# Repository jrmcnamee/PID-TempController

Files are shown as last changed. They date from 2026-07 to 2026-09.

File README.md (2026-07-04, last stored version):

# PID-TempController
Lab project to control the temperature of water using an Arduino and a PID algorithm

## Proportional-Integral-Derivative Algorithms
A Proportional-Integral-Derivative Algorithm can be used in controllers to minimize the difference betweent the output and the desired state of the system. A PID is a classic closed-loop feedback system, meaning it takes an input and then systematically compares current state to its input over time. The image below shows a simple version of a closed loop system. The PID is simple and easy to implement, making it an attractive choice for many automated processes.



There are many applications for the PID controller, but it's used most often in regulation. For example, the current goal for my PID is to simply regulate water temperature using a probe and heating rod.

### Walking 100 meters; example
So imagine you need to walk forward 100 meters for a sobriety test (**that is one demanding cop!**). Of course, you're sober, but the cop is having a bad night so he demands you walk exactly 100 meters. You only pass if you stop within 0.1 meters of the goal. If you think about it, this is a clever test, because drunk people do not understand control systems! Another rule: **you cannot stop until you're done, reverse, or speed up after slowing down!** This'll come into play in a second.

So, how do you proceed? Well, the cop gives you a watch that tells you your position every second, and you have a brain that sets your velocity with devastating accuracy. Thats easy! Just stop when the watch says 99.9. But wait, theres a caveat: the watch only updates every second. One miss-step near the goal and you fail, and the watch won't update fast enough to  So what you do first is select your **gain**. The gain is very simple: select your gain, multipy it by your distance, and then thats the new velocity you will walk. Since a fast human walking pace is 2.5 meters per second, you select a gain of 0.025, as 100 meters * 0.025 $$s^{-1}$$ is 2.5 m/s. Your distance to time graph will look something like this.

Your position will approach the goal asymptotically until you get within 0.1 meters. The cop is stunned, but daps you up for your incredible math abilities. Thankfully for you, you simple cannot walk fast enough to blow past your target. However, if it *were* possible to select a gain of, say, 1.9, your graph would look like 

So lets talk a little bit more of P, I, and D.
Note that in this example, you technically need that tolerance the cop gave, otherwise you never will really arrive at the destination.



## Proportional Gain, K<sub>p</sub>
Propotional gain was exemplified just before this in the walking example. Its a good way to correct your behavior as you approach the target. However, there are many ways for this to go wrong. Imagine that instead of walking, you're climbing, and gain * error sets the force you climb with. Obviously, you will stop dead in your tracks if the force you move up with ever equals the force of gravity, or your weight. This is called steady state error, and it will result in you never making it to the target. Also, think about it for a heating apparatus: if a certain amount of applied voltage corresponds to a certain amount of heat loss per minute and the rate of heat emmission by the heated system ever becomes equal, you'll be screwed. Whoops!

Proportional gain cannot account for steady state error, or mitigate oscillations. It's the principal component of gain, and extremely influential in the PID. Play around with it using my python code for a basic PID, it'll really shock you how much it governs the system! Try to see if you can get it to reach a steady state (hint: add a term of pushback against proportional gain!)

## Integral Gain, K<sub>i</sub>

Integral gain stockpiles error and provides a proportional signal to the integral over the time. Seems simple, right? This is a great solution to the steady state error connundrum, as persistant, constant error ultimately results in the increase of the provided signal, preventing stability anywhere other than the target. An appropriate integral gain coefficient will make a clean descent/ascent to the target, but one too large will result in "integral windup" which is this fun oscillating value over to the right. The integral and proportional terms should not exist without one another, as they cover eachothers' bases very well.

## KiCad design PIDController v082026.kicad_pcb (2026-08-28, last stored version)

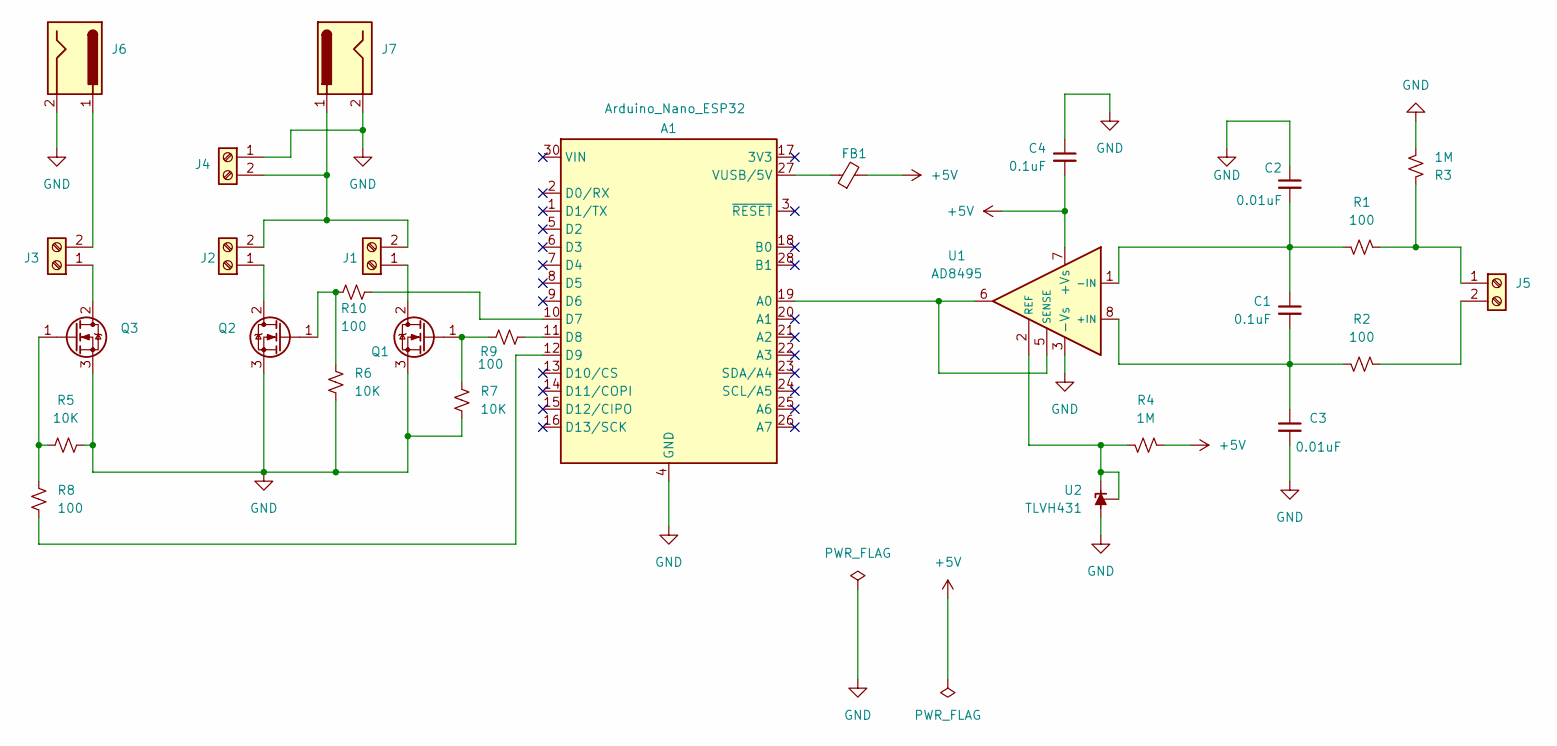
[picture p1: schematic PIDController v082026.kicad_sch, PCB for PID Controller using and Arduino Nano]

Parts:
A1: Arduino_Nano_ESP32; Arduino_Nano
C1, C4: 0.1uF; C_0603_1608Metric
C2, C3: 0.01uF; C_0603_1608Metric
FB1: FerriteBead_Small; L_0603_1608Metric
J1, J2, J3, J4, J5: Screw_Terminal_01x02; TerminalBlock_Phoenix_MKDS-1,5-2_1x02_P5.00mm_Horizontal
J6, J7: Jack-DC; BarrelJack_CUI_PJ-063AH_Horizontal
Q1, Q2, Q3: IRLZ44N; TO-220-3_Vertical
R1, R2, R8, R9, R10: 100; R_0603_1608Metric
R3, R4: 1M; R_0603_1608Metric
R5, R6, R7: 10K; R_0603_1608Metric
U1: AD8495; MSOP-8_3x3mm_P0.65mm
U2: TLVH431; SOT-23

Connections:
+5V: C4.2, FB1.2, R4.1, U1.7 (+Vs)
GND: A1.4 (GND), A1.29 (GND), C2.1, C3.2, C4.1, J4.1, J6.2, J7.2, Q1.3 (S), Q2.3 (S), Q3.3 (S), R3.2, R5.1, R6.2, R7.2, U1.3 (-Vs), U2.3 (A)
unnamed: A1.19 (A0), U1.5 (SENSE), U1.6
unnamed: A1.10 (D7), R10.2
unnamed: A1.11 (D8), R9.2
unnamed: A1.12 (D9), R8.2
unnamed: A1.27 (VUSB/5V), FB1.1
unnamed: J1.1, Q1.2 (D)
unnamed: J1.2, J2.2, J4.2, J7.1
unnamed: J2.1, Q2.2 (D)
unnamed: J3.1, Q3.2 (D)
unnamed: J3.2, J6.1
unnamed: J5.1, R1.1, R3.1
unnamed: J5.2, R2.1
unnamed: Q1.1 (G), R7.1, R9.1
unnamed: Q2.1 (G), R6.1, R10.1
unnamed: Q3.1 (G), R5.2, R8.1
unnamed: C1.2, C3.1, R2.2, U1.8 (+IN)
unnamed: C1.1, C2.2, R1.2, U1.1 (-IN)
unnamed: R4.2, U1.2 (REF), U2.1 (K), U2.2 (REF)

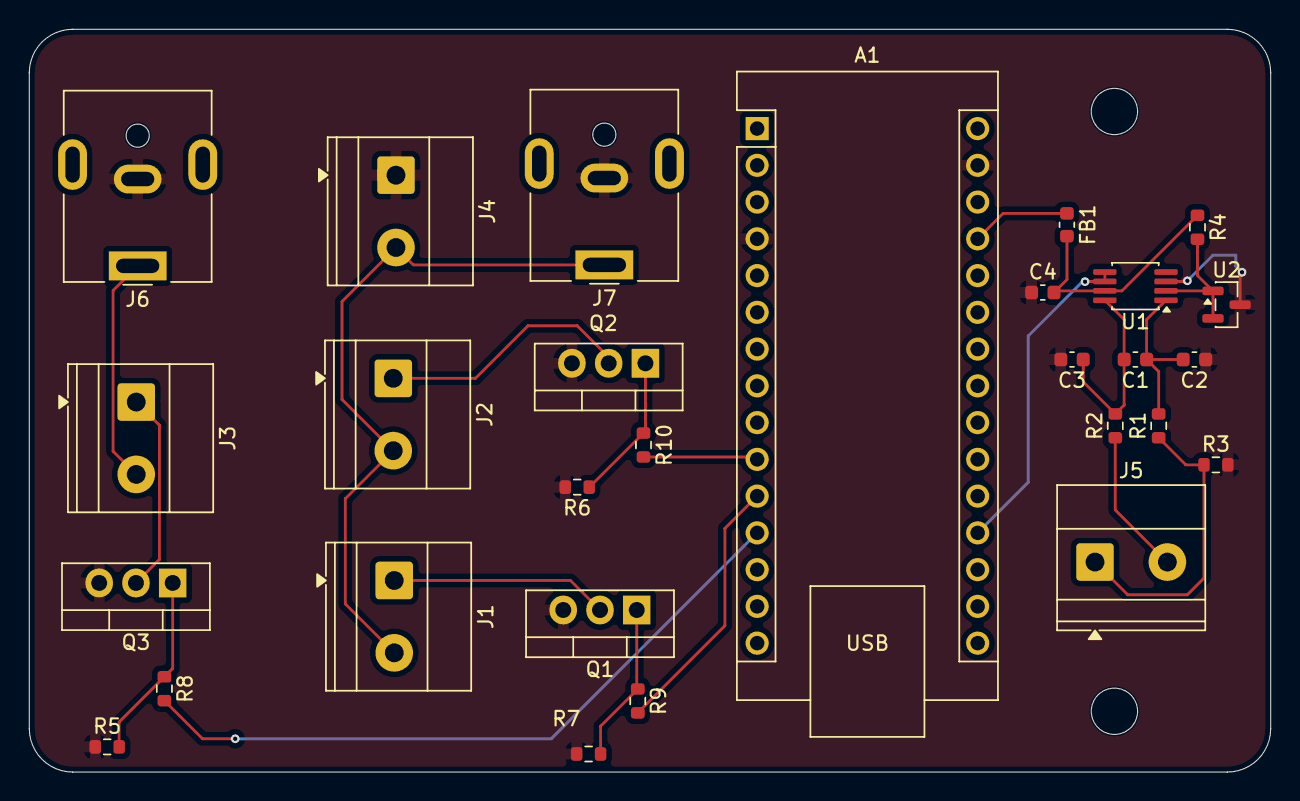
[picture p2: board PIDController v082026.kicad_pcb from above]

Board: 2 copper layers, 85.8 x 51.3 mm, 28 parts (0 on the bottom side), 20 nets.

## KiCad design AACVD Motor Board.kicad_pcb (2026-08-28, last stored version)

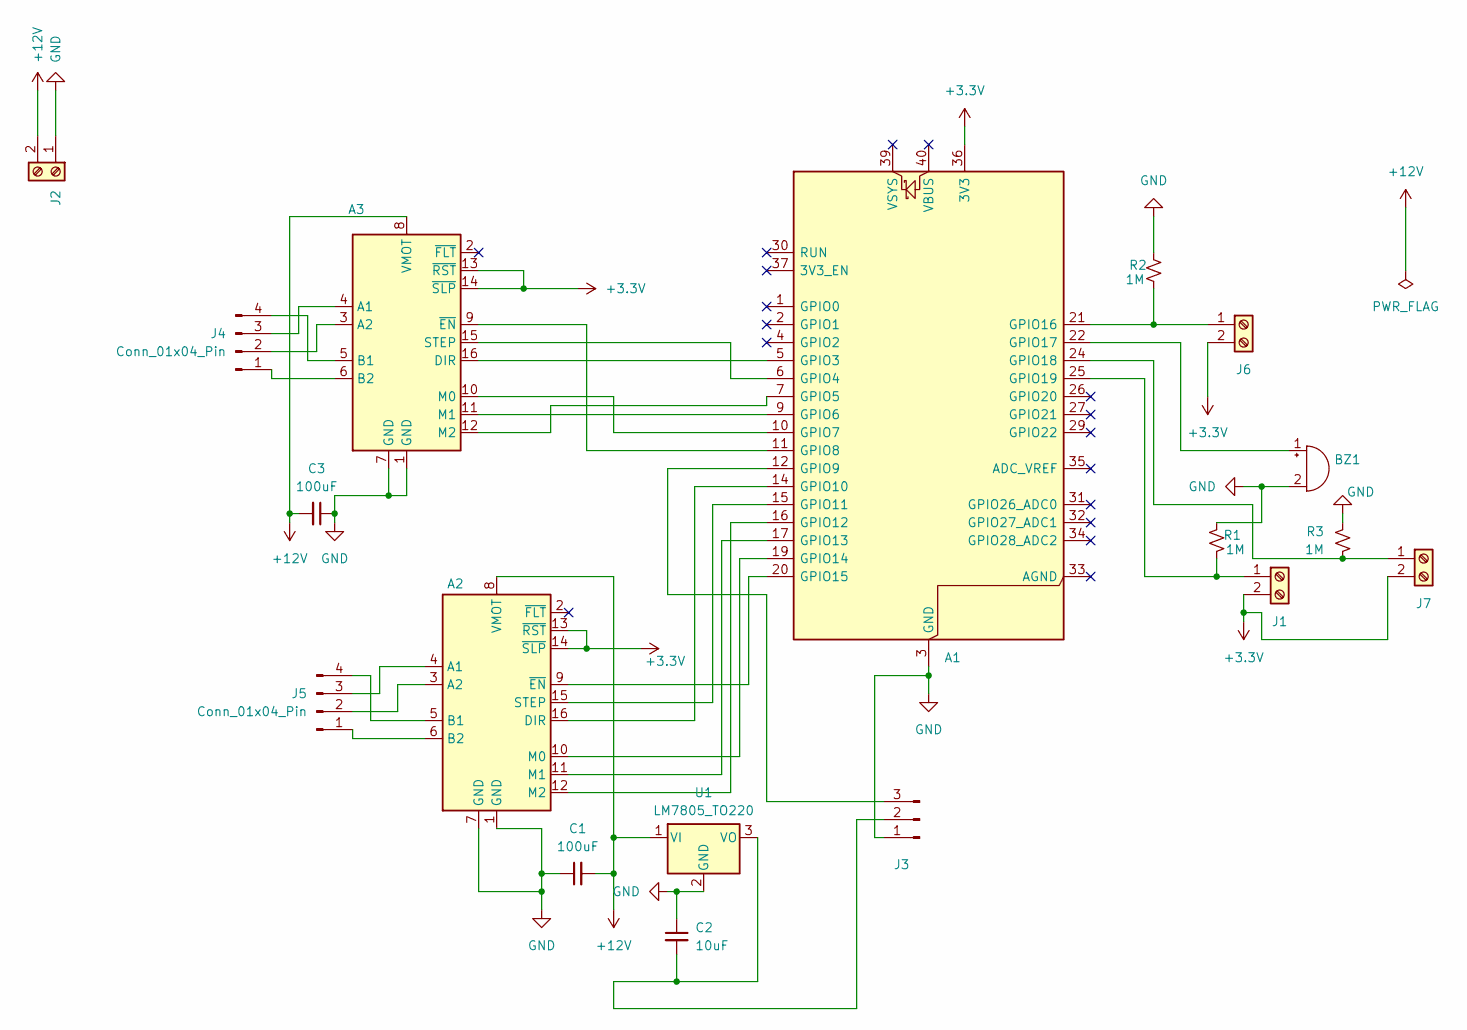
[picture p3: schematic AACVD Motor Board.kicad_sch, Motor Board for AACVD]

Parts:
A1: RaspberryPi_Pico; RaspberryPi_Pico_Common_Unspecified
A2, A3: Pololu_Breakout_DRV8825; Pololu_Breakout-16_15.2x20.3mm
BZ1: Buzzer; Buzzer_12x9.5RM7.6
C1, C3: 100uF; C_0603_1608Metric
C2: 10uF; C_0603_1608Metric
J1, J2, J6, J7: Screw_Terminal_01x02; TerminalBlock_Phoenix_MKDS-1,5-2_1x02_P5.00mm_Horizontal
J3: Conn_01x03_Pin; PinHeader_1x03_P2.54mm_Vertical
J4, J5: Conn_01x04_Pin; PinHeader_1x04_P2.00mm_Vertical
R1, R2, R3: 1M; R_0603_1608Metric
U1: LM7805_TO220; TO-220-3_Vertical

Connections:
+3.3V: A1.36 (3V3), A2.13 (~RST), A2.14 (~SLP), A3.13 (~RST), A3.14 (~SLP), J1.2, J6.2, J7.2
+12V: A2.8 (VMOT), A3.8 (VMOT), C1.2, C3.2, J2.2, U1.1 (VI)
GND: A1.3 (GND), A1.8 (GND), A1.13 (GND), A1.18 (GND), A1.23 (GND), A1.28 (GND), A1.38 (GND), A2.1 (GND), A2.7 (GND), A3.1 (GND), A3.7 (GND), BZ1.2 (-), C1.1, C2.1, C3.1, J2.1, J3.1, R1.1, R2.1, R3.1, U1.2 (GND)
unnamed: A1.5 (GPIO3), A3.16 (DIR)
unnamed: A1.6 (GPIO4), A3.15 (STEP)
unnamed: A1.7 (GPIO5), A3.12 (M2)
unnamed: A1.9 (GPIO6), A3.11 (M1)
unnamed: A1.10 (GPIO7), A3.10 (M0)
unnamed: A1.11 (GPIO8), A3.9 (~EN)
unnamed: A1.12 (GPIO9), J3.3
unnamed: A1.14 (GPIO10), A2.16 (DIR)
unnamed: A1.15 (GPIO11), A2.15 (STEP)
unnamed: A1.16 (GPIO12), A2.12 (M2)
unnamed: A1.17 (GPIO13), A2.11 (M1)
unnamed: A1.19 (GPIO14), A2.10 (M0)
unnamed: A1.20 (GPIO15), A2.9 (~EN)
unnamed: A1.21 (GPIO16), J6.1, R2.2
unnamed: A1.22 (GPIO17), BZ1.1 (+)
unnamed: A1.24 (GPIO18), J7.1, R3.2
unnamed: A1.25 (GPIO19), J1.1, R1.2
unnamed: A2.4 (A1), J5.3
unnamed: A2.3 (A2), J5.2
unnamed: A2.5 (B1), J5.4
unnamed: A2.6 (B2), J5.1
unnamed: A3.4 (A1), J4.3
unnamed: A3.3 (A2), J4.2
unnamed: A3.5 (B1), J4.4
unnamed: A3.6 (B2), J4.1
unnamed: C2.2, J3.2, U1.3 (VO)

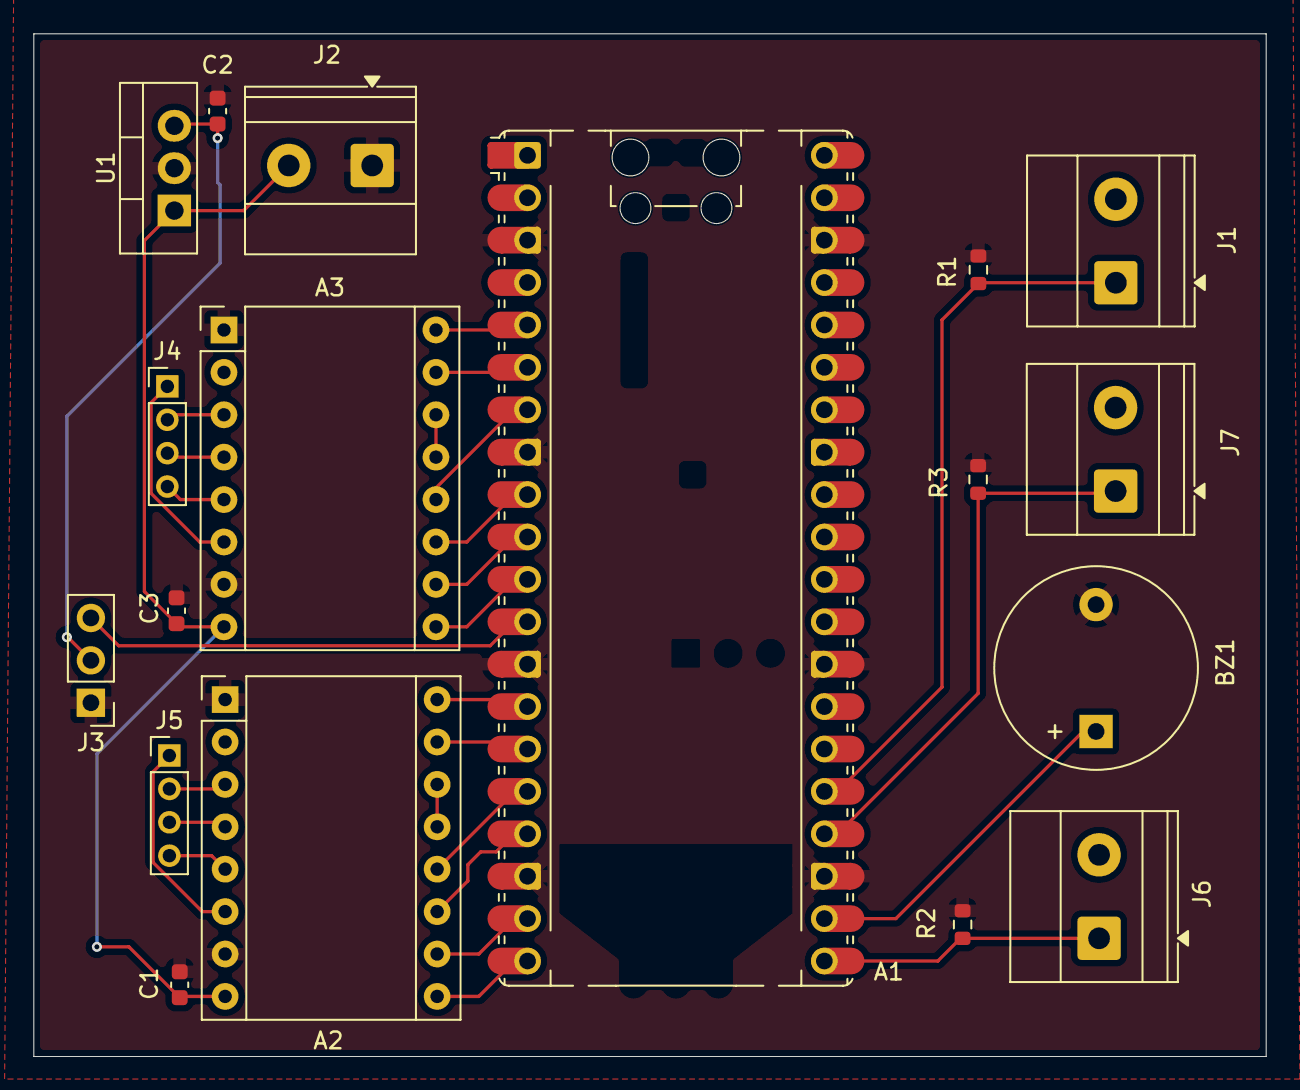
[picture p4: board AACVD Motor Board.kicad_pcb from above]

Board: 2 copper layers, 73.8 x 61.3 mm, 18 parts (0 on the bottom side), 29 nets.

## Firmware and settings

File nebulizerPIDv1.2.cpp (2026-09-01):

#include <Arduino.h>
#include <SPI.h>
#include "Adafruit_MAX31855.h"

unsigned long lastCommandTime = 0;
const unsigned long TIMEOUT_MS = 2000;

const int heaterPin = 10;
const int coolerPin = 9;
const int max31855_CLK = 5;
const int max31855_CS  = 4;
const int max31855_DO  = 3;
Adafruit_MAX31855 thermocouple(max31855_CLK, max31855_CS, max31855_DO);

// checks serial for initiator signal.
void checkSerial() {
  String command = Serial.readStringUntil('\n');
  command.trim();

  int separatorIndex = command.indexOf(':');

  if (separatorIndex != -1){
    String actionPart = command.substring(0, separatorIndex);
    String valuePart = command.substring(separatorIndex + 1);

    int actionID = actionPart.toInt();
    int targetValue = valuePart.toInt();

    executeAction(actionID, targetValue);
  }
}

void executeAction(int action, int value){
  switch(action){
    case 1:
      Serial.println(temperatureReading());
      break;
    
    case 2:
      setWattage(value);
      break;
      
  }


}
// reads temperature and sends it back to loop
double temperatureReading() {
  double celsius = thermocouple.readCelsius();

  // Check if the library returns a "NaN" (Not a Number) error code
  if (isnan(celsius)) {
    Serial.println("Error: Something is wrong with the thermocouple probe!");

    // Read the exact error register bits to diagnose the issue
    uint8_t exceptionBits = thermocouple.readError();
    if (exceptionBits & MAX31855_FAULT_OPEN)      Serial.println(" - Fault: Connection is open (No probe attached).");
    if (exceptionBits & MAX31855_FAULT_SHORT_GND) Serial.println(" - Fault: Thermocouple shorted to Ground.");
    if (exceptionBits & MAX31855_FAULT_SHORT_VCC) Serial.println(" - Fault: Thermocouple shorted to VCC.");

    return NAN;
  }
  else {
    return celsius;
  }
}

// sets the wattage by multiplying the computer signal by the max PWM value
void setWattage(float scalar) {
  if (scalar < 0){
    analogWrite(coolerPin, (int)(-scalar));
    analogWrite(heaterPin, 0);
  }
  else if (scalar > 0){
    analogWrite(heaterPin, (int)(scalar));
    analogWrite(coolerPin, 0);
  }
  else{
    analogWrite(coolerPin, 0);
    analogWrite(heaterPin, 0);
  }
}

void setup() {
  Serial.begin(9600);
  while (!Serial) {
    delay(10);
  }
  pinMode(heaterPin, OUTPUT);
  pinMode(coolerPin, OUTPUT);
}

void loop() {
  if (Serial.available() > 0) {
    checkSerial();
    lastCommandTime = millis();
  } else if (millis() - lastCommandTime > TIMEOUT_MS) {
    analogWrite(heaterPin, 0);
    analogWrite(coolerPin, 0);
  }
}

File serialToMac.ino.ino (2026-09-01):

void setup() {
  Serial.begin(9600); // Set the same baud rate in Python
}

void loop() {
  if (Serial.available() > 0) {
    // Read the incoming string until a newline character
    String incoming = Serial.readStringUntil('\n');
    
    // Print a response back to Python
    Serial.print("Mac sent: ");
    Serial.println(incoming);
  }
}

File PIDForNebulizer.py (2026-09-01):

#!/usr/bin/env python3
# -*- coding: utf-8 -*-
"""
Created on Tue Jul 21 15:47:58 2026

@author: jeffreymcnamee
"""

import serial
import time
import numpy as np

import communicationTools as comm ##functions in communicationTools.py are used for serial communication with the Arduino. These are the functions readProbe and sendSignal.
    
class controllerPID:
    def __init__ (self, PORT1, PORT2, heater_kp, heater_ki, heater_kd, cooler_kp, cooler_ki, cooler_kd, tau, heater_bool = True, cooler_bool = False):
        """
        Initializes the PID controller with the given parameters. 
        If heater_bool is True, the controller will use the provided heater PID parameters.
        If cooler_bool is True, the controller will use the provided cooler PID parameters.
        Otherwise, the controller will not use the corresponding PID parameters and will set the output limits accordingly.
        """
        if heater_bool:
            self.heater_kp = heater_kp
            self.heater_ki = heater_ki
            self.heater_kd = heater_kd
            self.MAX = 255
        else:
            self.MAX = 0
            self.heater_kp = 0
            self.heater_ki = 0
            self.heater_kd = 0
            
        if cooler_bool:
            self.cooler_kp = cooler_kp
            self.cooler_ki = cooler_ki
            self.cooler_kd = cooler_kd
            self.MIN = -255
        else:
            self.MIN = 0
            self.cooler_kp = 0
            self.cooler_ki = 0
            self.cooler_kd = 0
            
        self.integral = 0
        self.port1 = PORT1
        self.port2 = PORT2
        self.delay = tau
        self.RUN = True
        
    def controllerRun(self, target_temp):
        """
        Runs the PID controller to maintain the target temperature.
        Call this function to start the controller. It will continuously read the temperature from the probe, calculate the PID signal, and send it to the Arduino until the controller is stopped.
        """
        self.integral = 0
        arduino1 = serial.Serial(port=self.port1, baudrate=9600, timeout=1) ##this function opens the serial port to communicate with the Arduino. The baudrate and timeout are set to match the Arduino's settings.
        arduino2 = serial.Serial(port=self.port2, baudrate=9600, timeout=1)
        time.sleep(2)
    
        error = None
        while error is None:          # keep retrying the first read until it's valid
            temp = comm.readProbe(arduino2)
            if temp is not None:
                error = target_temp - temp
    
        while self.RUN == True:
            prev_error = error
            temp = comm.readProbe(arduino2)
            print(temp)
    
            if temp is None:
                # bad reading — skip this cycle, don't update PID state or send a signal
                time.sleep(self.delay)
                continue
    
            error = target_temp - temp
            signal = self.signalCalculator(error, prev_error)
            comm.sendSignal(arduino1, signal)
            time.sleep(self.delay)

        
    def closeController(self):
        """
        For the purpose of this tutorial, ignore this function and stop the controller by using the red box in the top right corner of the Kernel.
        In a real application, the controllerRun function would be running in a separate thread, and this function would be called to stop the controller gracefully.
        """
        self.RUN = False
        return

    def signalCalculator(self, error, prev_error):
        """
        This is the PID algorithm, nearly everything else is for the purpose of reading the temperature and sending the signal to the Arduino.
        If you want to change the PID parameters, do it in the __init__ function. If you want to change the delay between readings, do it in the __init__ function. 
        If you want to change the target temperature, do it in the controllerRun function.
        This function calculates the PID output using the independent gain equation. It also utilizes anti-windup to prevent the integral term from growing 
        too large when the output is saturated. The integral term is only updated when the output is not saturated or when the error is pushing the output back towards the unsaturated range.

        IT IS RECCOMENDED TO GET YOUR PID TO WORK WITH P AND I GAIN FIRST. START WITH D AT 0.
        """
        if error < 0: 
            p_term = self.cooler_kp * error
        elif error >= 0:
            p_term = self.heater_kp * error

        potential_integral = self.integral + self.delay * error
        if potential_integral < 0: 
            i_term = self.cooler_ki * potential_integral
        elif potential_integral >= 0:
            i_term = self.heater_ki * potential_integral

        derivative = (error-prev_error) / self.delay
        if error < 0: 
            d_term = self.cooler_kd * derivative
        elif error >= 0:
            d_term = self.heater_kd * derivative

        raw_output = p_term + i_term + d_term

        is_saturated = raw_output <= self.MIN or raw_output >= self.MAX
        pushing_further = (error > 0 and raw_output >= self.MAX) or \
                           (error < 0 and raw_output <= self.MIN)

        if not (is_saturated and pushing_further):
            self.integral = potential_integral

        if self.integral < 0: 
            i_term = self.cooler_ki * self.integral
        elif self.integral >= 0:
            i_term = self.heater_ki * self.integral
            
        output = p_term + i_term + d_term
        
        if output<2:
            output=0
            
        print(max(self.MIN, min(output, self.MAX)))
        return max(self.MIN, min(output, self.MAX))

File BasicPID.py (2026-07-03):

# -*- coding: utf-8 -*-
"""
Spyder Editor

This is a temporary script file.
"""

import matplotlib.pyplot as plt

class PIDController:
    def __init__(self, kp, ki, kd, setpoint=0):
        self.kp = kp
        self.ki = ki
        self.kd = kd
        self.setpoint = setpoint
        self.integral = 0
        self.prev_error = 0

    def update(self, measured_value, dt):
        error = self.setpoint - measured_value
        p_term = self.kp * error
        
        self.integral += error * dt
        i_term = self.ki * self.integral

        derivative = (error - self.prev_error) / dt if dt > 0 else 0
        d_term = self.kd * derivative

        self.prev_error = error
        return p_term + i_term + d_term


# Setup
pid = PIDController(kp=1.2, ki=0.1, kd=0.93975, setpoint=100)
# Kp 1.2, ki 0.1, kd 0.93975 produces a state where the signal bounces between +/- 1031.1936065995408

dt = 0.1
n_steps = 10000
current_value = 0
time_data = []
value_data = []
setpoint_data = []
control_data = []

for step in range(n_steps):
    t = step * dt
    control_value = pid.update(current_value, dt)
    print(control_value)
    current_value += control_value * dt  # simple system model

    time_data.append(t)
    value_data.append(current_value)
    setpoint_data.append(pid.setpoint)
    control_data.append(control_value)

# Plot
fig, (ax1, ax2) = plt.subplots(2, 1, figsize=(9, 7), sharex=True)

ax1.plot(time_data, value_data, label="OVR Value", linewidth=2)
ax1.plot(time_data, setpoint_data, '--', label="Setpoint", color="gray")
ax1.set_ylabel("Value")
ax1.set_title("PID Response")
ax1.legend()
ax1.grid(True)

ax2.plot(time_data, control_data, label="Control Signal", color="orange")
ax2.set_xlabel("Time (s)")
ax2.set_ylabel("Control Signal")
ax2.legend()
ax2.grid(True)

plt.tight_layout()
plt.show()

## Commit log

2026-07-03 Enhance README with PID algorithm explanation
    Added a section explaining Proportional-Integral-Derivative algorithms.
2026-07-03 Enhance README with PID algorithm details and examples
    Expanded explanation of PID algorithms and their applications, including a walking example to illustrate proportional gain concepts.
2026-07-03 Fix typo in README about PID controller usage
2026-07-03 Basic PID code
    Good skeleton code for when you want a PID controller. Good for learning and as a sandbox. The plots are for visualization, feel free to comment them out.
2026-07-04 Enhance README with detailed PID algorithm explanations
    Updated the README to improve clarity and detail on PID algorithms, including changes to the proportional gain section and added information on integral gain.
2026-07-04 Enhance README with PID control explanations
    Added a note about the necessity of tolerance in reaching the destination and expanded on Proportional Gain in the context of PID control.
2026-07-27 Updated the PID algorithms generally for cooler. Worked on the class code.
2026-07-27 Refactor command sending to Arduino
2026-07-27 Implement rate limiting for control signal
    Added rate limiting to the control signal to prevent abrupt changes.
    [PIDForNebulizer.py]
2026-07-27 Add Arduino.h include for compatibility
2026-08-03 Refactor PID logic and implement controllerPID class
    Refactor PID control logic and add controllerPID class.
2026-08-03 Add communication functions for Arduino control
    Implemented functions to communicate with Arduino for sending commands and reading temperature.
2026-08-03 Update sendCommand to accept arduino parameter
2026-08-03 Refactor PID controller and remove unused code
    Refactor PID controller initialization and run method to accept target temperature. Remove commented-out code for clarity.
2026-08-09 Refactor PID controller methods and imports
2026-08-11 Refactor PID controller to support dual Arduino ports
2026-08-28 Custom PCB files
    [AACVD Motor Board.kicad_pcb, AACVD Motor Board.kicad_sch, PIDController v082026.kicad_pcb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]
